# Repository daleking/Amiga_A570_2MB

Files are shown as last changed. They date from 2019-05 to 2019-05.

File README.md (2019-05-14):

# 2MB RAM Expansion for the A570 CD-ROM Drive

This is a simple 2MB RAM expansion as others have done for the A570.  It is
simply an implementation of the Commodore schematics.  People have done these
before but frustratingly I couldn't find any gerbers to make my own, hence this
implementation.

The PCB layout could be better - feel free to rework it.  But as it is, the
card is perfectly stable and works well.  I used 514400J 1Mx4 SOJ DRAM chips
which are easy to find.  Interestingly 424400 chips don't work (at least the
ones I tried) giving a black / blinking screen, so better to stick with what
CBM specified on the schematics.

For the lazy, you can order gerbers from
[DirtyPCBs](http://dirtypcbs.com/store/designer/details/dalek/6305/2mb-ram-expansion-for-the-amiga-a570-cd-rom-drive)
or from your own board house (see the releases page), or remix how you like
with KiCAD.

If you scrounge old single sided 4MB or dual sided 8MB 72-pin PC SIMMs you will
probably find some suitable DRAM.

You will also need a 2x20pin female right angle header, and some decoupling
caps.  The schematics say 0.33uF but I used 0.1uF with no issues and it even
works if you leave the caps off.

The jumper is the RAM enable jumper.  Connect it to a wired external switch if
you really feel you want to be able to disable the RAM without opening the
cover again.

## Schematic
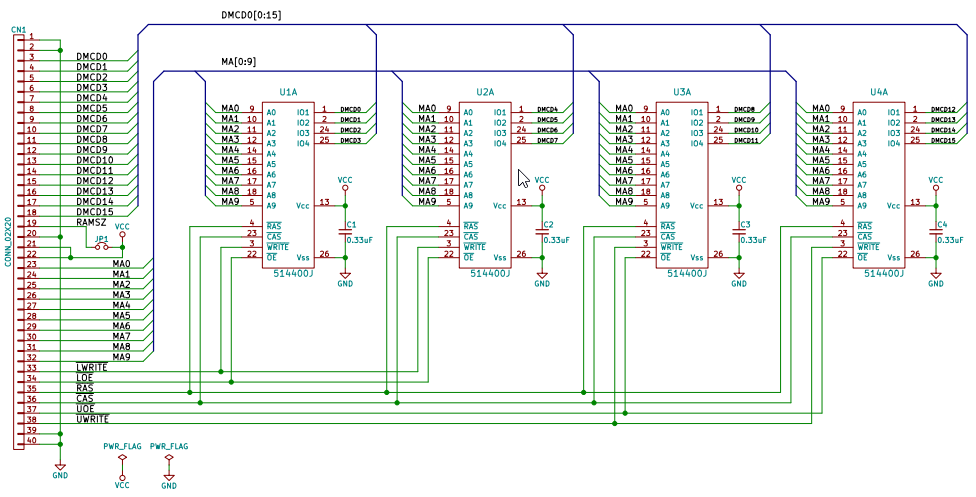
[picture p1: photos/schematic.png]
schematic


## Front
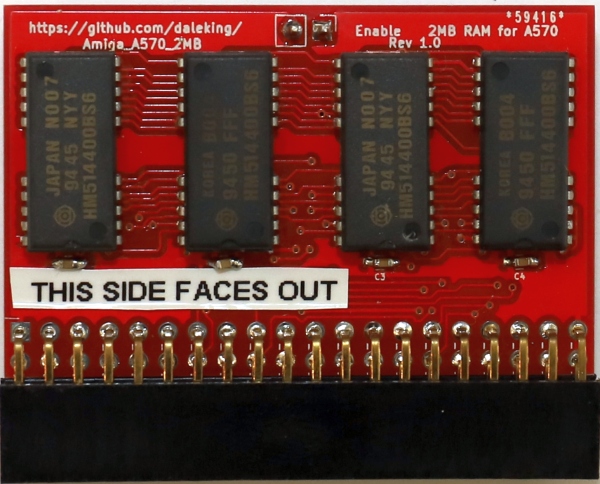
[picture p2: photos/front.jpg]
top


## Bottom
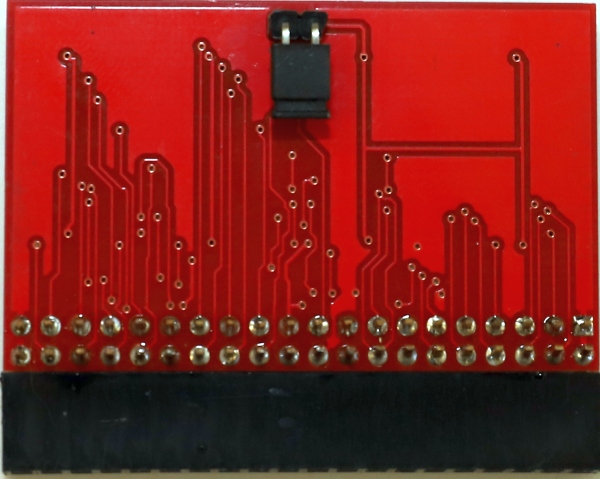
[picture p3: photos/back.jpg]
bottom


## Connected
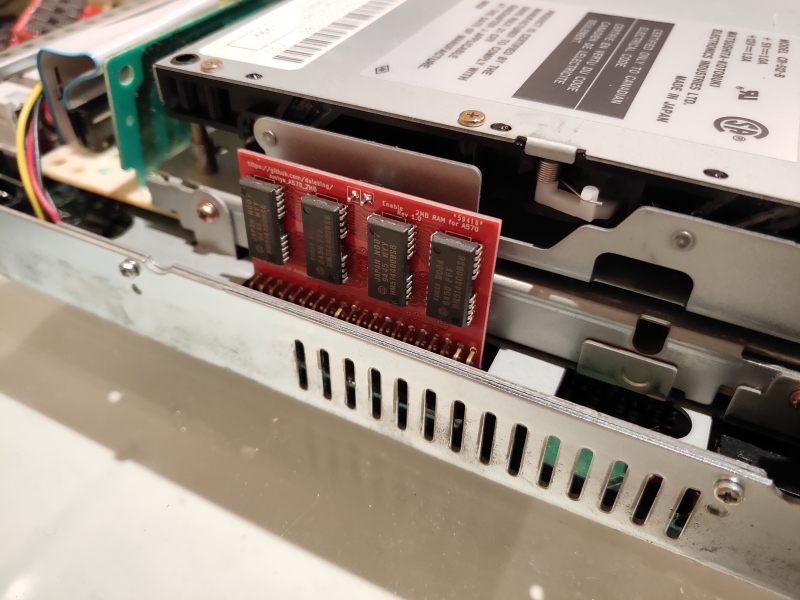
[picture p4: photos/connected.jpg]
connected


## Memory Test
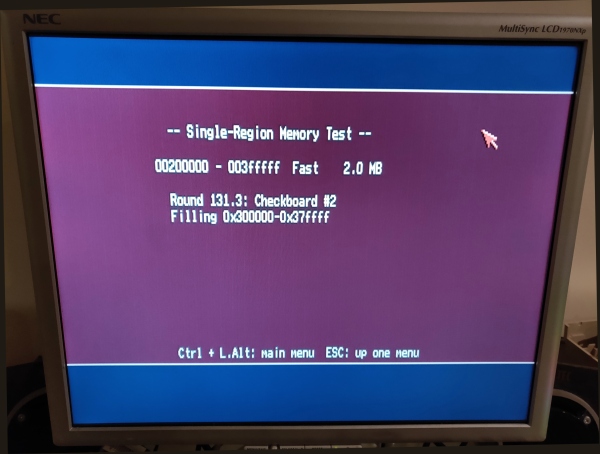
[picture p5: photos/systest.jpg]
systest


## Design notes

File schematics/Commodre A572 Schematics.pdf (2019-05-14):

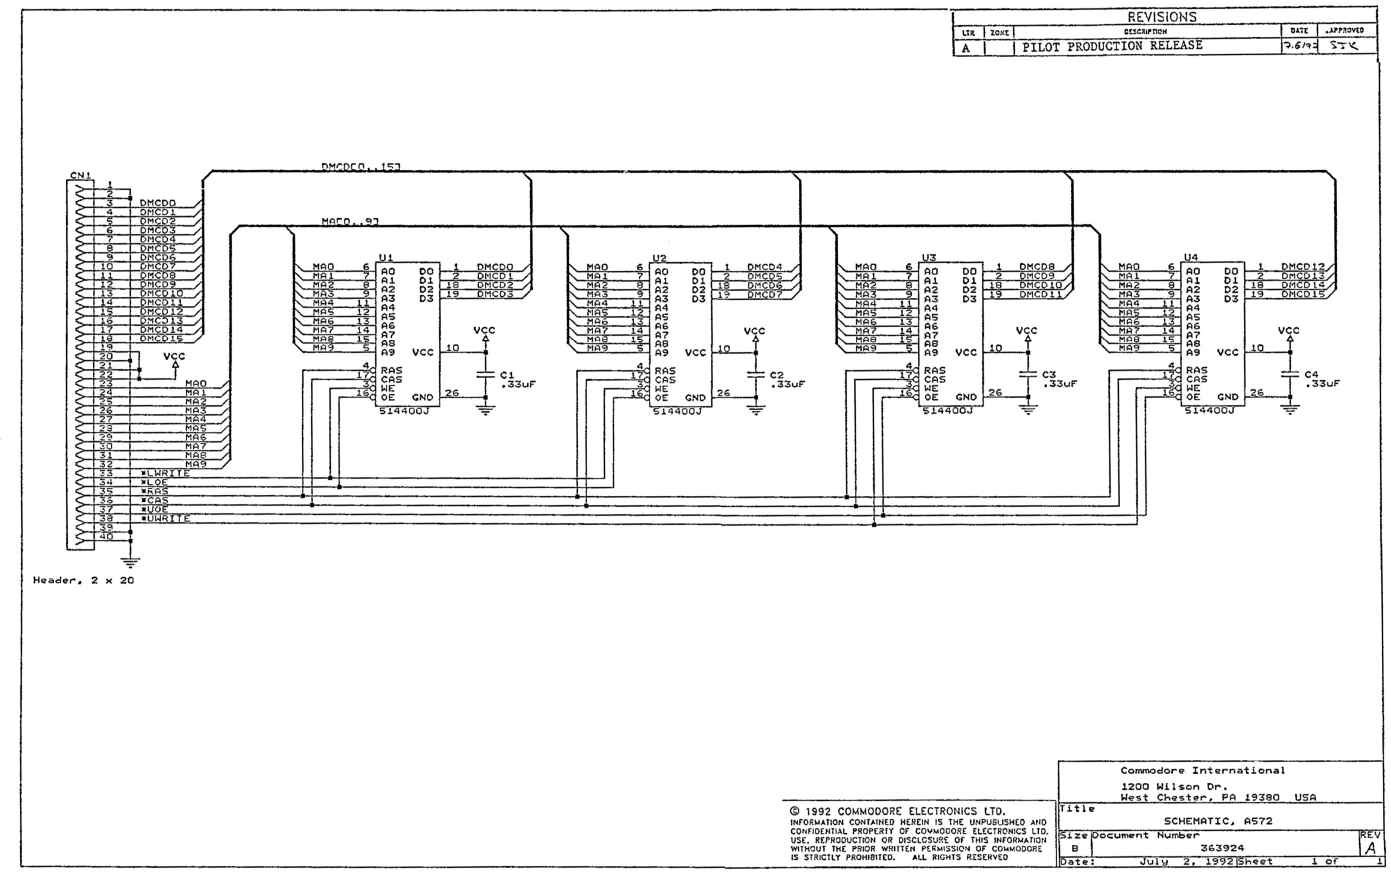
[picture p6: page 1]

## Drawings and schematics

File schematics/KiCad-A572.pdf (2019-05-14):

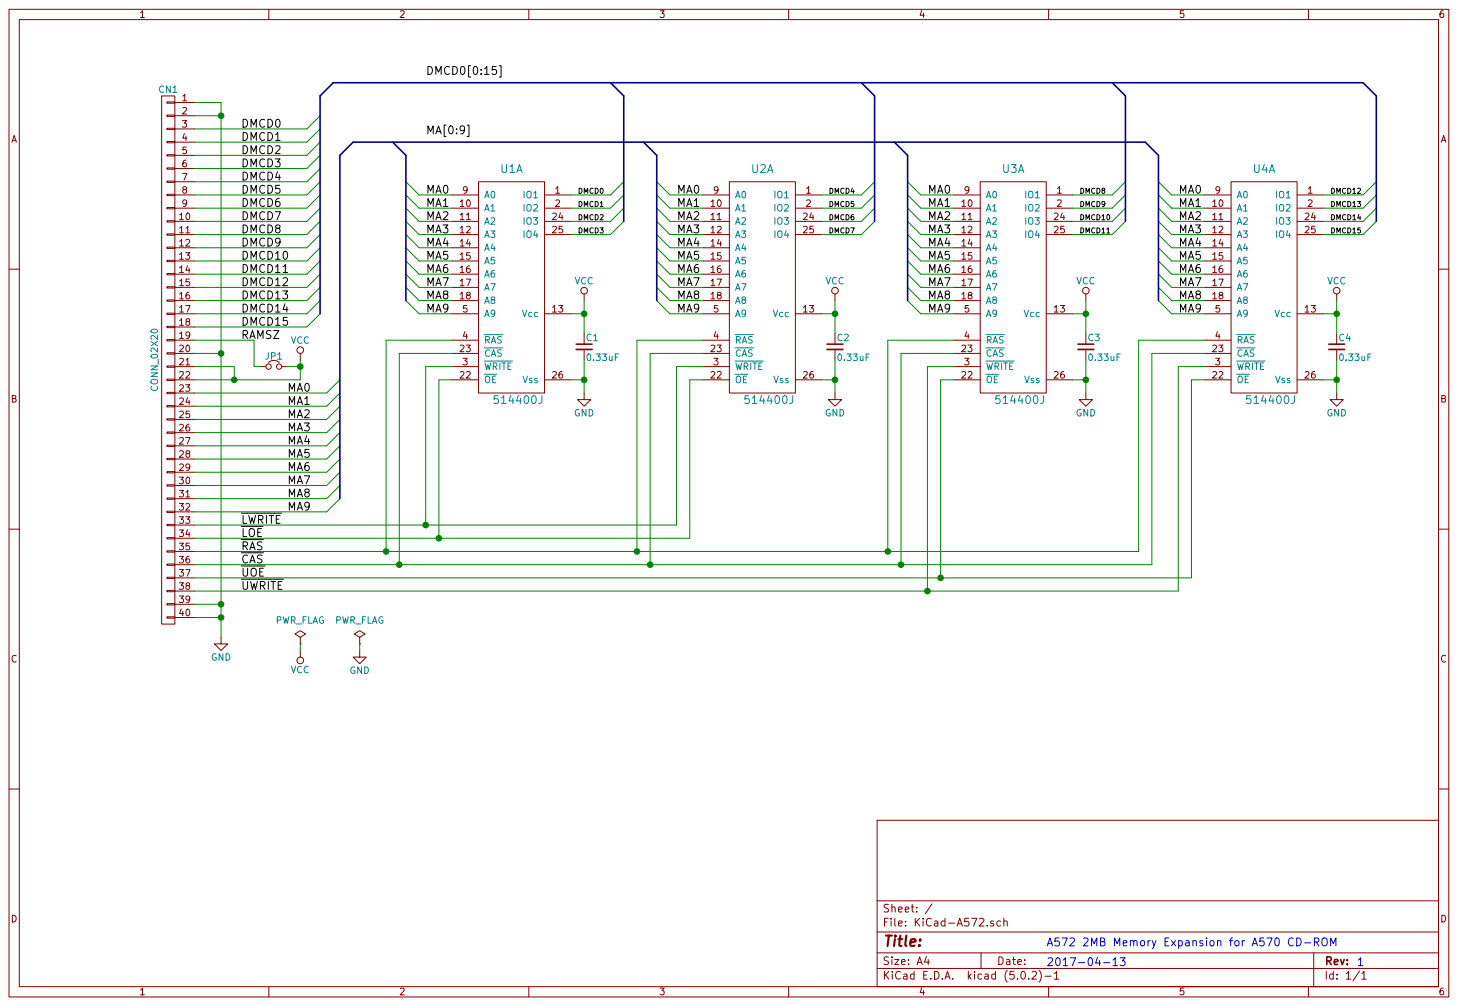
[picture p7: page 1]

3 4 5 6 7 8 10 11 12 13 14 15 16 17 18 19

20
21
22
23 24 25 26 27 28 29 30 31 32 33

34 | | LOE
35 | RAS
36 | CAS
37 | UOE UWRITE
38
39
40

Id: 1/1 Title: File: KiCad-A572.sch Sheet: /

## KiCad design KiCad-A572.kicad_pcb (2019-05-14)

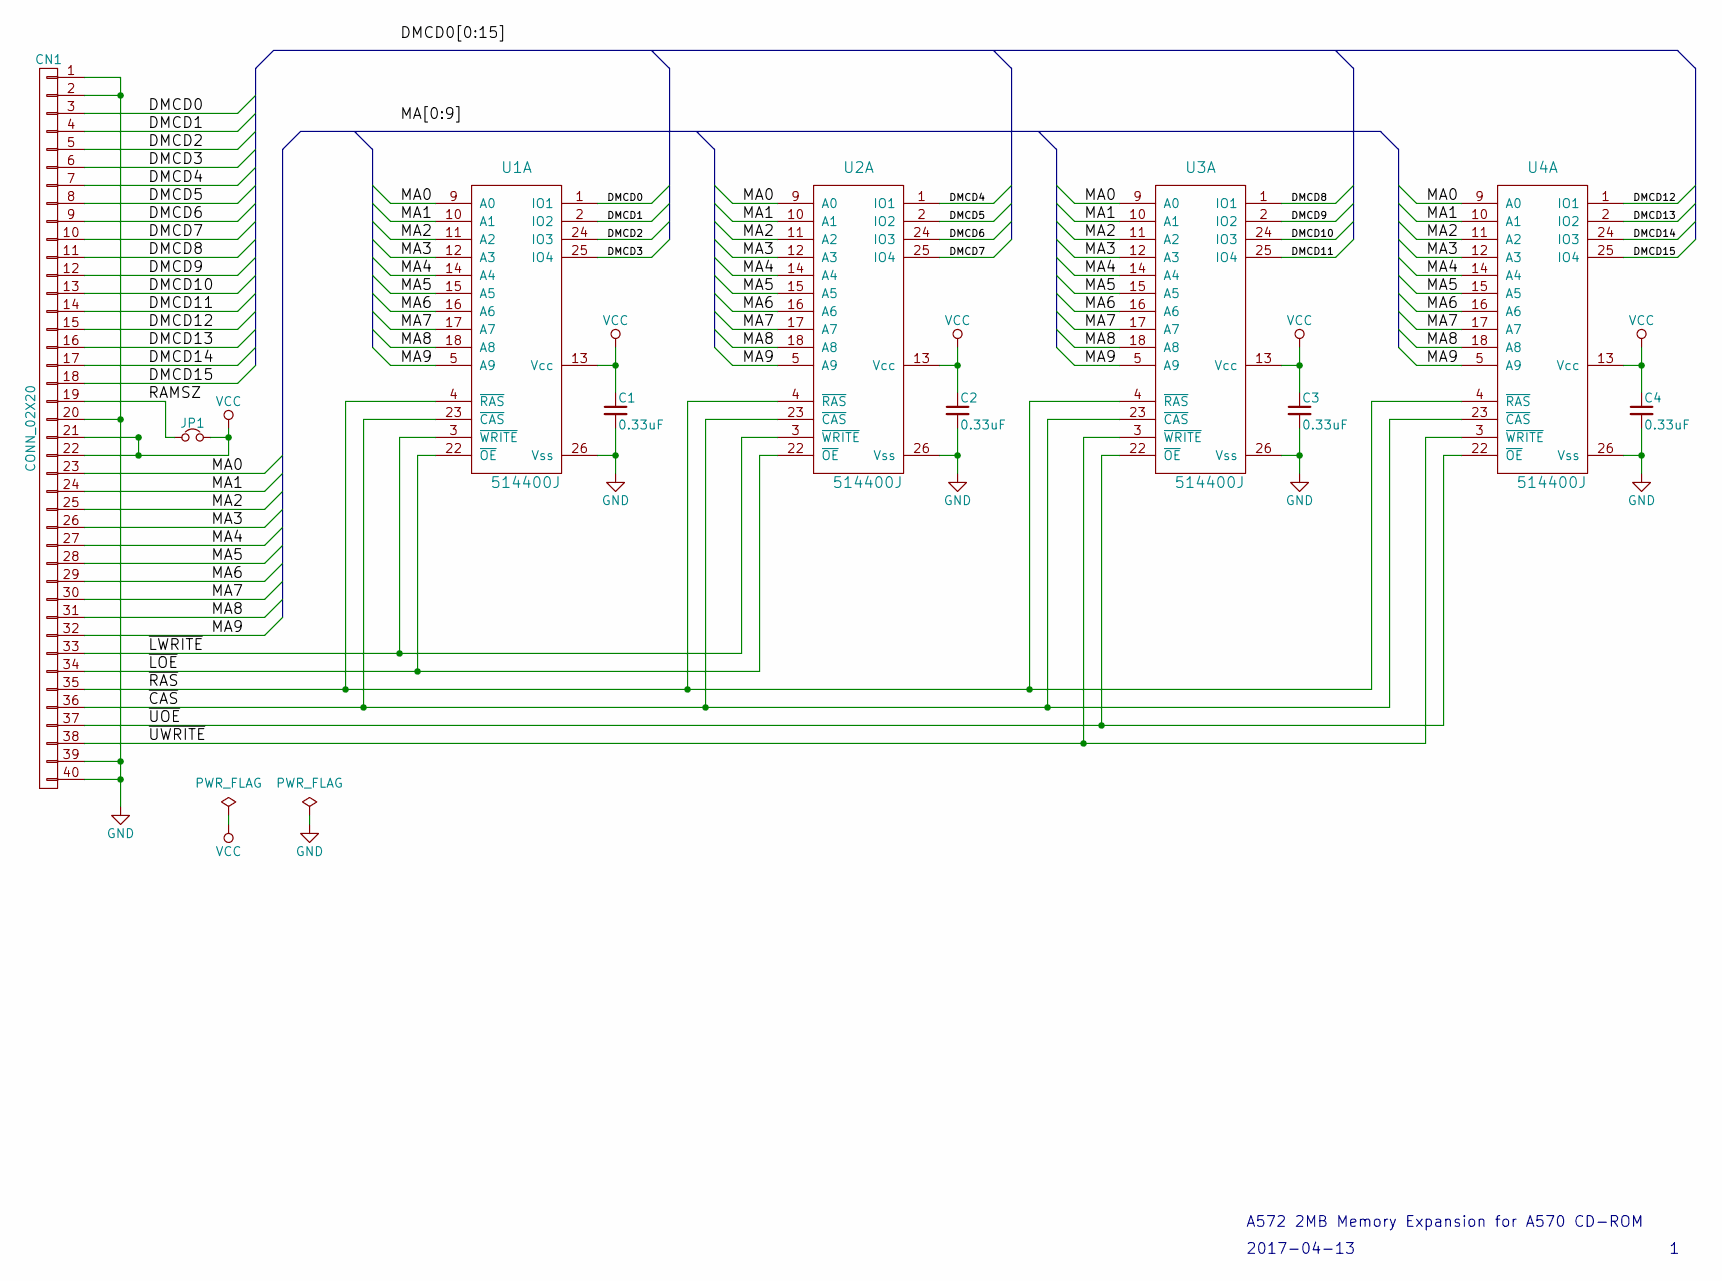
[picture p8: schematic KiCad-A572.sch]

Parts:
C1, C2, C3, C4: 0.33uF; C_0603_HandSoldering
CN1: CONN_02X20; Socket_Strip_Angled_2x20_Pitch2.54mm
JP1: Jumper_NC_Small; Pin_Header_Angled_1x02_Pitch2.54mm
U1, U2, U3, U4: 514400J; SOJ-20-26

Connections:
/DMCD0: CN1.3, U1.1 (IO1)
/DMCD1: CN1.4, U1.2 (IO2)
/DMCD2: CN1.5, U1.24 (IO3)
/DMCD3: CN1.6, U1.25 (IO4)
/DMCD4: CN1.7, U2.1 (IO1)
/DMCD5: CN1.8, U2.2 (IO2)
/DMCD6: CN1.9, U2.24 (IO3)
/DMCD7: CN1.10, U2.25 (IO4)
/DMCD8: CN1.11, U3.1 (IO1)
/DMCD9: CN1.12, U3.2 (IO2)
/DMCD10: CN1.13, U3.24 (IO3)
/DMCD11: CN1.14, U3.25 (IO4)
/DMCD12: CN1.15, U4.1 (IO1)
/DMCD13: CN1.16, U4.2 (IO2)
/DMCD14: CN1.17, U4.24 (IO3)
/DMCD15: CN1.18, U4.25 (IO4)
/MA0: CN1.23, U1.9 (A0), U2.9 (A0), U3.9 (A0), U4.9 (A0)
/MA1: CN1.24, U1.10 (A1), U2.10 (A1), U3.10 (A1), U4.10 (A1)
/MA2: CN1.25, U1.11 (A2), U2.11 (A2), U3.11 (A2), U4.11 (A2)
/MA3: CN1.26, U1.12 (A3), U2.12 (A3), U3.12 (A3), U4.12 (A3)
/MA4: CN1.27, U1.14 (A4), U2.14 (A4), U3.14 (A4), U4.14 (A4)
/MA5: CN1.28, U1.15 (A5), U2.15 (A5), U3.15 (A5), U4.15 (A5)
/MA6: CN1.29, U1.16 (A6), U2.16 (A6), U3.16 (A6), U4.16 (A6)
/MA7: CN1.30, U1.17 (A7), U2.17 (A7), U3.17 (A7), U4.17 (A7)
/MA8: CN1.31, U1.18 (A8), U2.18 (A8), U3.18 (A8), U4.18 (A8)
/MA9: CN1.32, U1.5 (A9), U2.5 (A9), U3.5 (A9), U4.5 (A9)
/RAMSZ: CN1.19, JP1.1
/~CAS: CN1.36, U1.23 (~CAS), U2.23 (~CAS), U3.23 (~CAS), U4.23 (~CAS)
/~LOE: CN1.34, U1.22 (~OE), U2.22 (~OE)
/~LWRITE: CN1.33, U1.3 (~WRITE), U2.3 (~WRITE)
/~RAS: CN1.35, U1.4 (~RAS), U2.4 (~RAS), U3.4 (~RAS), U4.4 (~RAS)
/~UOE: CN1.37, U3.22 (~OE), U4.22 (~OE)
/~UWRITE: CN1.38, U3.3 (~WRITE), U4.3 (~WRITE)
GND: C1.2, C2.2, C3.2, C4.2, CN1.1, CN1.2, CN1.20, CN1.39, CN1.40, U1.26 (Vss), U2.26 (Vss), U3.26 (Vss), U4.26 (Vss)
VCC: C1.1, C2.1, C3.1, C4.1, CN1.21, CN1.22, JP1.2, U1.13 (Vcc), U2.13 (Vcc), U3.13 (Vcc), U4.13 (Vcc)

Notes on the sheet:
A572 2MB Memory Expansion for A570 CD-ROM
2017-04-13

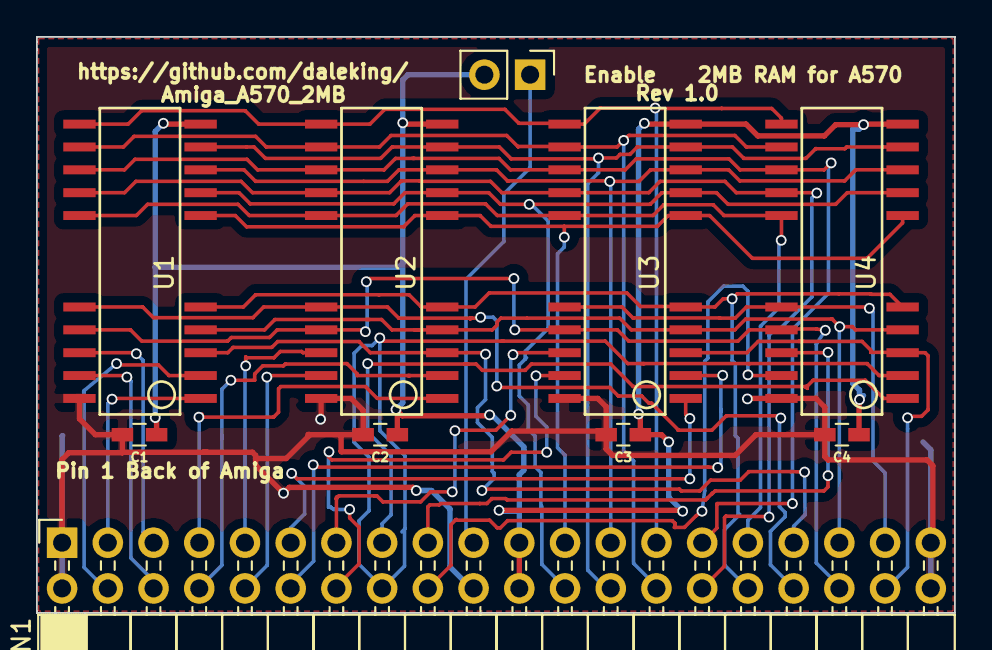
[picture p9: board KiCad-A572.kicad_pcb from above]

Board: 2 copper layers, 51.0 x 32.0 mm, 10 parts (0 on the bottom side), 35 nets.
